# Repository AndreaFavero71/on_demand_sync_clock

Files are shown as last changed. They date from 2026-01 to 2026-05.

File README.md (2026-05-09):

# on_demand_sync_clock
On-Demand Sync Clock (OSC), an open-source, DIY smart table clock that calibrates itself with one touch of a button.

<br><br>
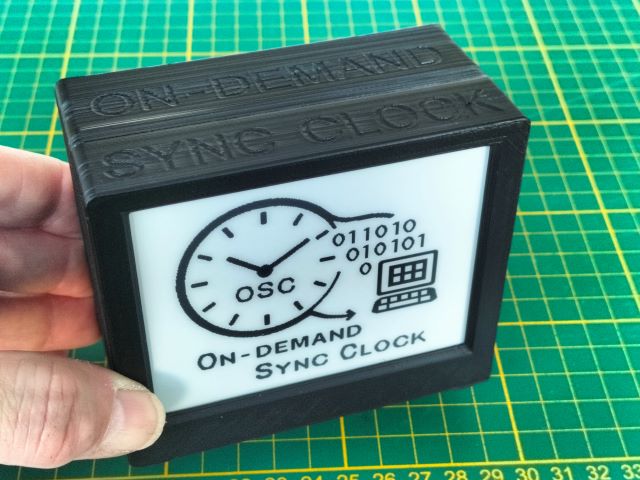
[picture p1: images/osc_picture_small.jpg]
title image
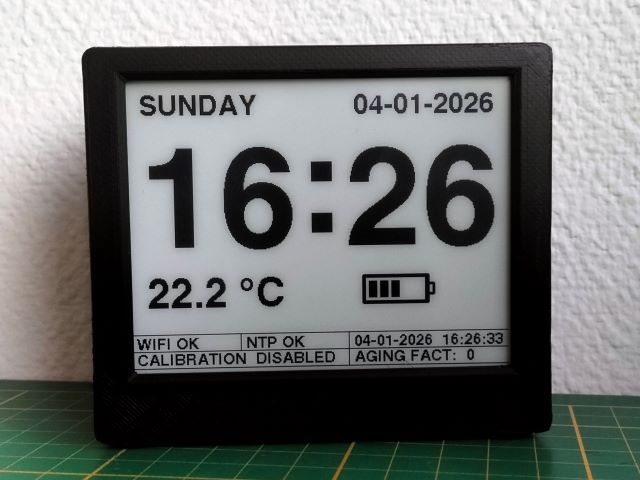
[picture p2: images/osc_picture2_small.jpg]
title image


The distinctive feature of this clock is its effortless adjustment: Simply press the push-button while an open network (Wi-Fi without password) is available, for instance, a smartphone hotspot.

Timekeeping is handled by a DS3231SN Real-Time Clock (RTC) module, which features a temperature-compensated crystal oscillator. According to the datasheet, its accuracy is within ±2 ppm (approximately ±1 minute per year).

When the button is pressed, the clock synchronizes with NTP servers. If at least 14 days have passed since the previous sync, it also calculates the drift and automatically adjusts the DS3231SN’s internal aging factor to improve long-term accuracy.

This automatic calibration is particularly handy, as many DS3231 chips on the market (in all versions, SN included) are clones with lower precision.

In short, the On-demand Sync Clock (OSC) is a DIY smart table clock that synchronizes with NTP servers on-demand via a button press, calibrates its RTC drift automatically, and runs for months on a battery.

This makes the OSC a practical option for any location without permanent internet access.

<br><br>
## Repo content
- all the Micropython files
- the Gerber files to make the Connections board
- the step files

<br><br>
## Videos
Very short video of the **sync** process (https://youtu.be/xEnDS9yevQY)
Watch the Demo (https://youtu.be/xEnDS9yevQY)
<br><br><br>

Very short video of the DS3231 **calibration** process (https://youtu.be/2SDDaN3pt_c)
Watch the Demo (https://youtu.be/2SDDaN3pt_c)

<br><br><br>
## For more information
More detailed informations at my [Instructables page](https://www.instructables.com/On-demand-Sync-Clock-OSC/)

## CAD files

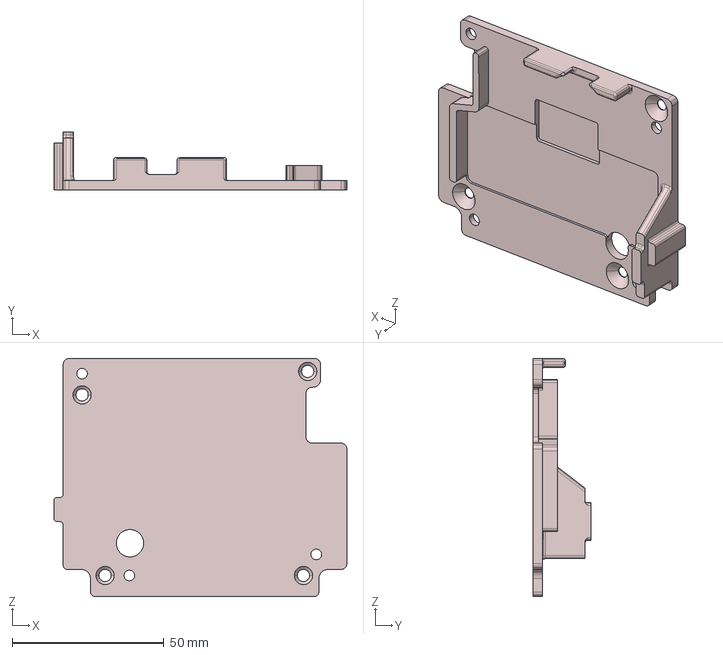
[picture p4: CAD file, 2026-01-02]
3d_model/step/panel.stp
96.5 x 19.0 x 78.4 mm

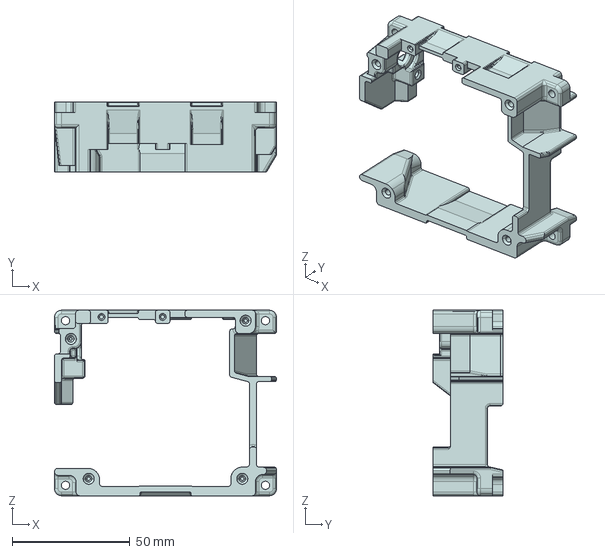
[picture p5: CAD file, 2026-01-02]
3d_model/step/frame.stp
94.4 x 29.7 x 78.9 mm

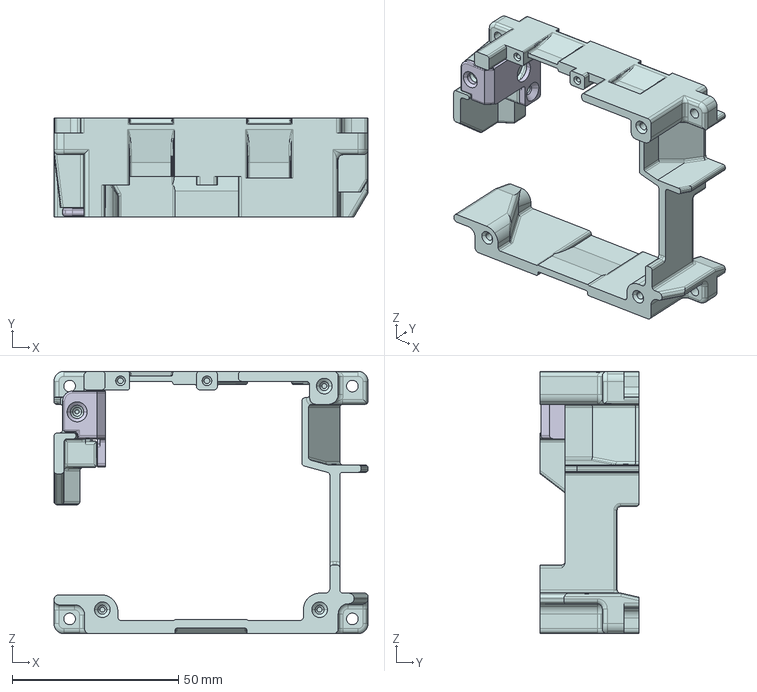
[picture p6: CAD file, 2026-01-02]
3d_model/step/btn_support.stp
94.4 x 29.7 x 78.9 mm

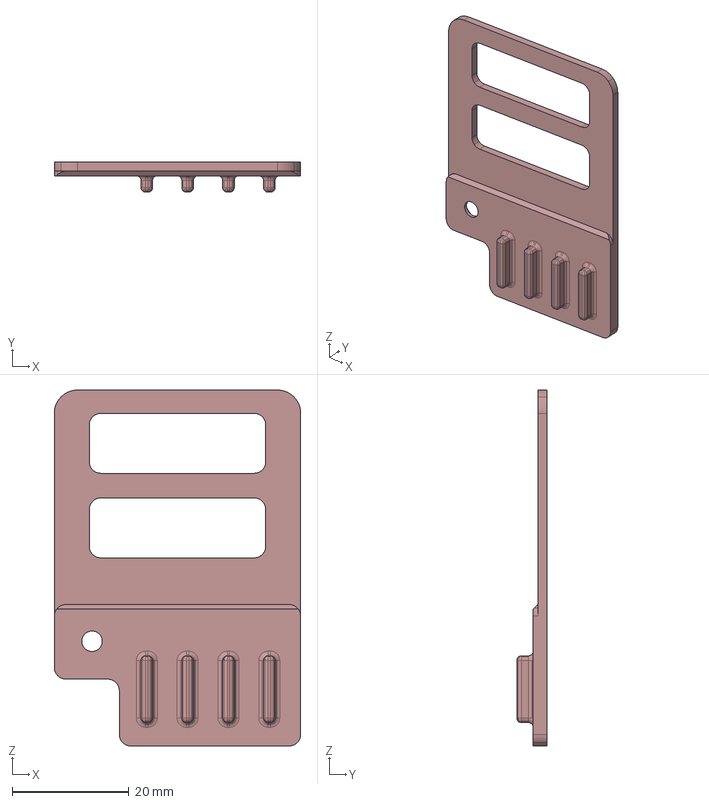
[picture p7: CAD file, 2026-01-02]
3d_model/step/clip.stp
42.3 x 5.20 x 61.0 mm

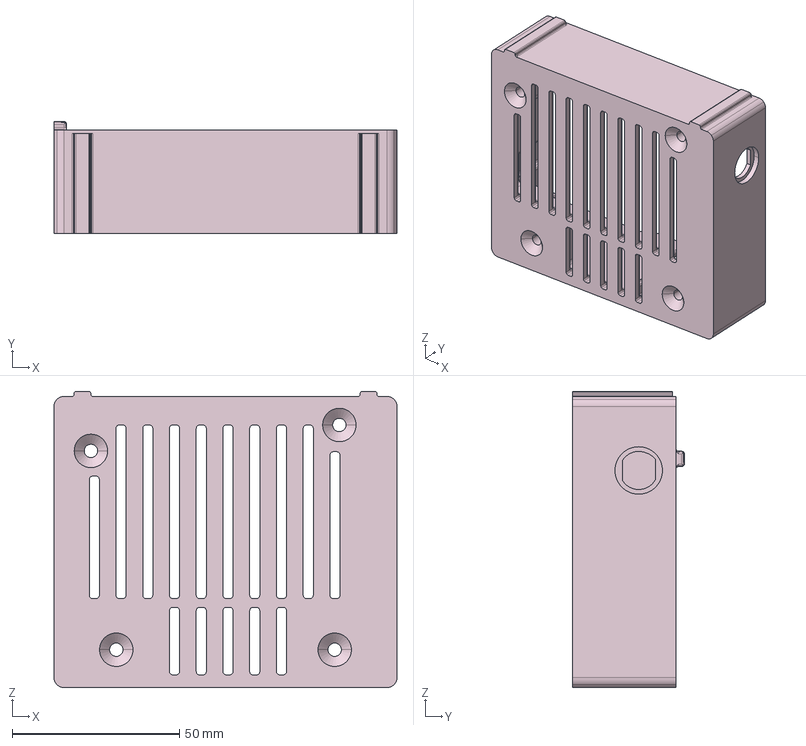
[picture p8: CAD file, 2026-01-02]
3d_model/step/back_LP785060.stp
102.6 x 33.4 x 88.6 mm

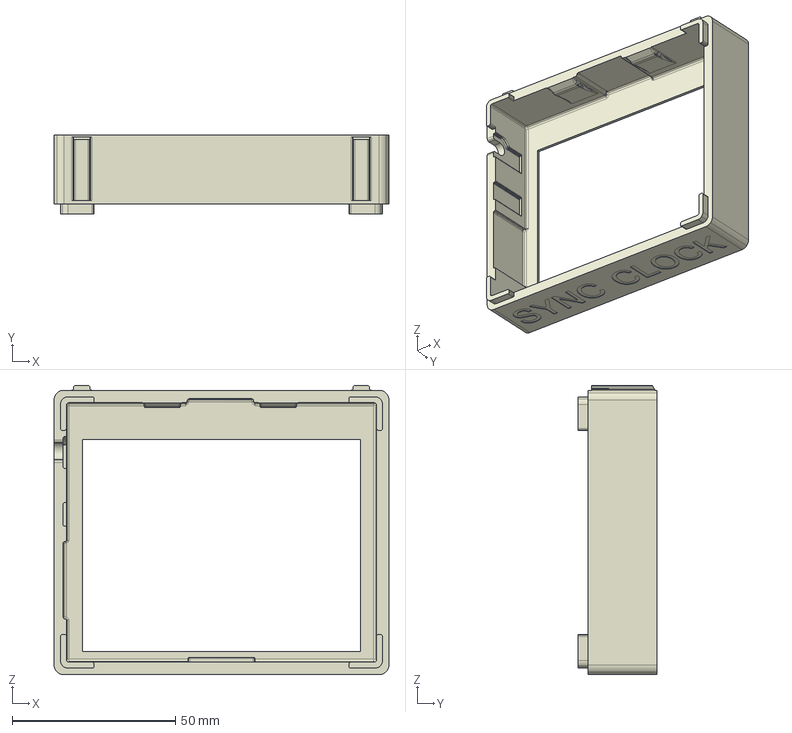
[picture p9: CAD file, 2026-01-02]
3d_model/step/front.stp
102.6 x 24.1 x 88.6 mm

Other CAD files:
3d_model/stl/btn_support.stl
3d_model/stl/clip.stl
3d_model/stl/panel.stl

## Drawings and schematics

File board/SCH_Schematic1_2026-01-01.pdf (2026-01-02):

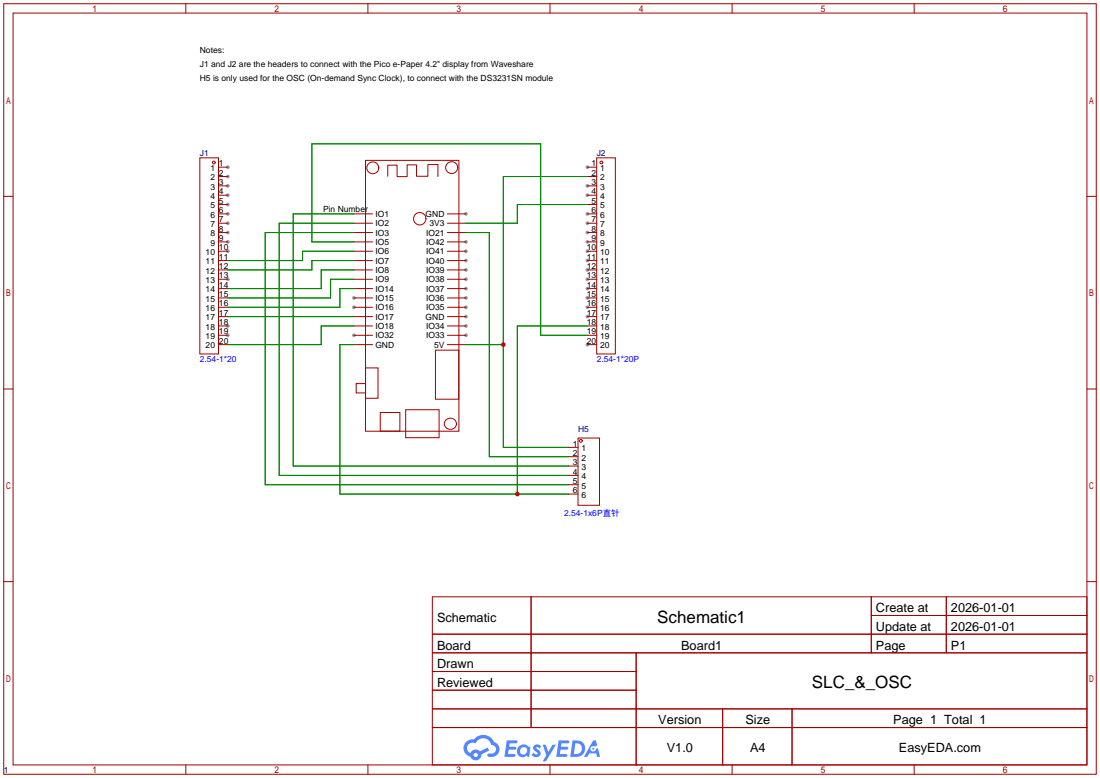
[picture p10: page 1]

Notes:
J1 and J2 are the headers to connect with the Pico e-Paper 4.2" display from Waveshare
H5 is only used for the OSC (On-demand Sync Clock), to connect with the DS3231SN module

Schematic | Schematic1 | Create at | 2026-01-01

Update at | 2026-01-01

Board | Board1 | Page | P1
Drawn | | SLC_&_OSC
Reviewed

Version | Size | Page 1 Total 1
V1.0 | A4 | EasyEDA.com

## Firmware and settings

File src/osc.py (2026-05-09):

"""
Andrea Favero 20260505

On-demand Sync Clock (OSC), a smart digital clock

The main distinctive feature is its easy sync and calibration, via
the push button and Wi-Fi coverage (also open Wi-Fi), resulting in:
- DS3231SN sync, if less than 14 days from previous sync.
- DS3231SN calibration, if more than 14 days from previous sync.


The clock is based on
- LiLyGO TTGO T8-S3 board (v1.2)      [https://tinyurl.com/3tyy9sea]
- DS3231SN module                     [https://tinyurl.com/3vp7n53h]
- WaveShare 4.2" epaper Pico display  [https://www.waveshare.com/wiki/Pico-ePaper-4.2]

High level info:
- UTC is retrieved from NTP the first time the clock runs, and on request via the push button.
- UTC is stored at the RTC DS3231.
- TZ and DST are dinamically applied on the retrieved time from the RTC DS3132, for display purpose.
- When saving UTC to theRTC, then TZ and DST are saved to NVS; This allows to precisely calculate the
  aging factor also when a DST change has happened in the meanwhile.
- No WiFi hospot is required when the clock boots after ESP32 shut-off due to low battery voltage.


More info at:
  https://github.com/AndreaFavero71/on_demand_sync_clock
  https://www.instructables.com/On-Demand-sync-Clock-OSC/


MIT License

Copyright (c) 2026 Andrea Favero

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
__version__ = "0.0.5"

# import standard modules
from utime import ticks_ms, sleep_ms, ticks_diff, mktime
from machine import Pin, freq, lightsleep
import uasyncio as asyncio
from esp32 import NVS, wake_on_ext0, WAKEUP_ANY_HIGH
import sys, gc

# import OSC custom modules
from network_manager import NetworkManager
from time_manager import TimeManager
from display_manager import Display
from battery_manager import Battery
from wdt_manager import WDTManager
from lib.config import config

# pin used to energize the DS3231ZN module
NTP_SYNC_PIN = 21


class SelfLearningClock:
    def __init__(self, logo_time_ms):
        
        print()
        print("#" * 41)
        print("#  Clock started. Press Ctrl+C to stop  #")
        print("#" * 41)
        print()
        
        # lower ESP32-S3 frequency to reduce power consumption (80MHz is the minimum for wlan operation)
        freq = 80_000_000
        
        # check / make a folder for the log related files
        self._make_folder("log")
        
        # initialize the ntp_sync_pin imput pin to start a NTP Sync
        self.ntp_sync_pin = Pin(NTP_SYNC_PIN, Pin.IN, Pin.PULL_DOWN)
        
        # enable the GPIO as a wake source from lightsleep
        wake_on_ext0(pin=self.ntp_sync_pin, level=WAKEUP_ANY_HIGH)
        
        # initialize the module for time management
        self.time_mgr = TimeManager(config)
        
        # initialize WDT manager, before the modules where it is passed
        self.wdt_manager = WDTManager()
        
        # initialize display module, by also passing the WDT manager
        self.display = Display(wdt_manager = self.wdt_manager,
                               lightsleep_active = config.LIGHTSLEEP_USAGE,
                               battery = config.BATTERY,
                               degrees = config.TEMP_DEGREES,
                               hour12 = config.HOUR_12_FORMAT,
                               am_pm_label = config.AM_PM_LABEL,
                               debug = config.DEBUG,
                               logo_time_ms = logo_time_ms
                               )
        
        self.display.plot_osc(text=False, show_ms=0, lightsleep_req=False)
        
        # initialize the network manager module, by also passing the WDT manager
        self.network_mgr = NetworkManager(self.wdt_manager, try_open_networks=config.OPEN_NETWORKS)

        # check if error from initializing the network manager
        if not self.network_mgr.secrets:
            self.display.text_on_logo("ERROR: SECRETS.JSON", x=-1, y=-1, show_time_ms=2_000)
            sys.exit(1)
            
        # initialize the battery manager module, if set at config file
        if config.BATTERY:
            self.battery = Battery(debug=config.DEBUG)
            self.batt_voltage = 0
            self.batt_level = 0

            # frequent battery check (6 minutes) when charging, otherwise less frequent (60 minutes)
            self.battery_chrg = True
        
        # initialize WDT after all components are initialized
        self.wdt_manager.initialize() 
        
        # initialize global variables: EPD refresh time is at least 60 secs (nominal)
        self.display_interval_ms = max(60_000, config.DISPLAY_REFRESH_MS)

        # state variables
        self.forced_cycle = True        # it serves as first cycle and for forced cycles (i.e. on-demand NTP sync)
        self.upload_files = False       # flag to book the file uploading task to be executed at the convenient moment
        self.enable_cal = False         # disables the self calibration until config.MIN_TIME_AUTO_CAL_H time has elapsed
        self.cycle_counter = 0          # more for fun than needed, it counts all the cycles (525600 cycles a year)
        self.display_update_count = 0   # counter to limit partial epd refreshes in between full refreshes
        
        # unit variables
        self.degrees = config.TEMP_DEGREES
        
        # aging (calibration) variable is instantiated as zero
        # It gets overruled by the aging values from esp32.NVS or DS3231
        self.aging = 0

        # arbitrary initial temperature value
        self.ds3231_temp = -999
    
    
    
    
    def get_reset_reason(self):
        """Checks the reason for the MCU boot"""
        import machine
        
        # getattr tries to get 'BROWN_OUT_RESET' from machine module. If not available, it return 6.
        BROWN_OUT_RESET = getattr(machine, "BROWN_OUT_RESET", 6)

        reset_reason = machine.reset_cause()
        
        reset_map = {
            machine.PWRON_RESET:     "POWER-ON RESET",
            machine.HARD_RESET:      "HARD RESET",
            machine.WDT_RESET:       "WATCHDOG RESET",
            machine.DEEPSLEEP_RESET: "DEEPSLEEP WAKE",
            machine.SOFT_RESET:      "SOFT RESET",
            BROWN_OUT_RESET:         "BROWNOUT RESET"
            }
        
        reset_message = reset_map.get(reset_reason, f"???: {reset_reason}")
        
        del machine
        
        return reset_reason, reset_message
    
    
    
    
    def log_reset_reason(self, reset_reason, reset_msg):
        """Writes the reset reason to a text file."""
           
        # refresh the wdt
        self.network_mgr.feed_wdt(label="write_rst_reason")
            
        try:
            datetime = await self.time_mgr.get_DS3231_time()
            
            # measure the battery voltage and related level 
            batt_voltage, batt_level = self.battery.check_battery()
            
            if datetime is None:
                datetime = ('time not known')
            
            with open(config.RESET_FILE_NAME, "a") as file:
                file.write(f"Time: {datetime},  RST_reason: {str(reset_reason)},  RST_msg: {str(reset_msg)},  Batt_volt: {str(round(batt_voltage,3))}\n")

        except OSError as e:
            print(f"[ERROR]   Failed to write reset reason: {e}")
    
    
    
    
    def _get_nvs_val(self, key, default=None, text="DEBUG"):
        """
        Read data from esp.nvs.
        Different keys are used: 'aging', 'tz_dst', 'battery_low'
        """

        try:
            nvs = NVS("app_data")
            value = nvs.get_i32(key)   # get_i32 returns an integer
            
            if config.DEBUG:
                if key == "aging":
                    print(f"[DEBUG]    Aging factor at esp32.nvs is {value}")
                
                elif key == "tz_dst":
                    print(f"[{text}]    A tz_dst (Time Zone and DST correction) was available at esp32.nvs, value: {value}")
                
                elif key == "battery_low":
                    state = True if value == 1 else False
                    print(f"[DEBUG]    Low battery flag at esp32.nvs is {state}")
            return value
        
        except OSError as e:
            print(f"[ERROR] NVS Read {key}: {e}")
            
            if e.errno == -0x1102:
                print(f"[DEBUG]    Variable '{key}' not found in esp32.NVS")
            else:
                print(f"[ERROR]    Issue on reading from esp32.NVS: {e}")
            return default
    
    
    
    
    def _set_nvs_val(self, key, value):
        """
        Wite data to esp.nvs.
        Different keys are used: 'aging', 'tz_dst', 'battery_low'
        """

        try:
            nvs = NVS("app_data")
            nvs.set_i32(key, int(value))
            nvs.commit()
            state = True if value == 1 else False
            print(f"[DEBUG]    Set {state} to the key '{key}' of esp32.NVS")
            
            return True
        except Exception as e:
            print(f"[ERROR]    NVS Save {key}: {e}")
            return False
    
    
    
    
    def goto_sleep(self, total_sleep_ms):
        """Function handling the needed steps to enter lightsleep"""
        
        # refresh the wdt
        self.network_mgr.feed_wdt(label="goto_sleep_1")

        # ensures the sleep time being positive
        total_sleep_ms = max(0, total_sleep_ms)
        
        # case lightsleep is set False
        if not config.LIGHTSLEEP_USAGE:
            # The normal sleeping function is used, instead of the light sleep
            # The sleep is done in chunk, to check the NTP button as per lighsleep
 
            if config.DEBUG:
                awake_time_ms = ticks_diff(ticks_ms(), self.t_out_sleep)
                if awake_time_ms < 1.5 * config.DISPLAY_REFRESH_MS:
                    print(f"[DEBUG]    MCU awake for {awake_time_ms} ms")
                print(f"[DEBUG]    Going to sleep for {total_sleep_ms} ms")

            sleep_chunk_ms = 10
            t_ref_ms = ticks_ms()
            wake_triggered = False
            while ticks_diff(ticks_ms(), t_ref_ms) < total_sleep_ms:
                sleep_ms(sleep_chunk_ms)
                if self.ntp_sync_pin.value():
                    t_ref2_ms = ticks_ms()
                    while self.ntp_sync_pin.value():
                        if ticks_diff(ticks_ms(), t_ref2_ms) > 250:
                            print("[DEBUG]    GPIO interrupt simulated — break sleep!")
                            wake_triggered = True
                            break
                        sleep_ms(10)
                if wake_triggered:
                    break
        
        # case lightsleep is set True
        elif config.LIGHTSLEEP_USAGE:

            try:
                # disables the wifi, otherwise the light sleep does not start
                if self.network_mgr.wlan is not None and (self.network_mgr.wlan.active() or self.network_mgr.wlan.isconnected()):
                    wlan_disabling_t_ms = self.network_mgr.disable_wifi()
                    if total_sleep_ms > wlan_disabling_t_ms:
                        total_sleep_ms -= wlan_disabling_t_ms
                    else:
                        total_sleep_ms = 0
            except Exception as e:
                if config.DEBUG:
                    print(f"[ERROR]   Issue at goto_sleep when config.LIGHTSLEEP_USAGE: {e}")
                
            
            # refresh the wdt
            self.network_mgr.feed_wdt(label="goto_sleep_2")
            

            if config.DEBUG:
                # MCU awake time (in ms)
                print(f"[DEBUG]    MCU awake for {ticks_diff(ticks_ms(), self.t_out_sleep)} ms")
                
                # MCU lighsleep time to wake up jsut in time for the minute change
                print(f"[DEBUG]    Entering lightsleep for {total_sleep_ms} ms")
                
                # force the buffer to get empyied
                sys.stdout.flush()

                # short sleep to allow the data trasmission (UART/USB); from 10ms to 50ms should do
                sleep_ms(10)
            
            # call the light sleep function, passing the sleeping time in mS
            lightsleep(total_sleep_ms)
            
            #######################################################################
            ###### DBEBUG #########################################################
            #
            # This is only for debug the lightsleep part without lighsleep function
            # It prevents the serial communication from dropping.
            # Note the display_manager.py uses lightsleep function too.
            #
            # comment out lightsleep(total_sleep_ms) above
            # uncomment command below
#             sleep_ms(total_sleep_ms)
            #
            #######################################################################
            #######################################################################
            
            if config.DEBUG:
                print(f"[DEBUG]    Quitting lightsleep")
        
        # refresh the wdt
        self.network_mgr.feed_wdt(label="goto_sleep_3")
    
    
    
    
    async def run(self):
        """Main clock execution"""
        
        # retieve the reset reason
        reset_reason, reset_msg = self.get_reset_reason()
        print(f"\n[INFO]     Last reset reason: {reset_msg}\n")
        
        # writes the reset reason in a text file for later reference
        await self.log_reset_reason(reset_reason, reset_msg)
        
        # plot the OSC logo with the OSC code version
        self.display.text_on_logo(f"OSC  VERSION:  {__version__}", x=-1, y=-1, show_time_ms=5000)
        
        # check the aging factor at the DS3231SN and at ESP32 NVS
        self.aging = await self._check_aging_factor()
        
        # set use_wifi variable as True
        use_wifi = True
        
        # case battery is set True
        if config.BATTERY:
            # check the last battery_low flag saved at the esp32.nvs
            battery_low_nvs = self._get_nvs_val(key="battery_low")
            
            # list of messages suggesting a reboot after a power outage
            reboot_msg_low_energy = ("POWER-ON RESET", "BROWNOUT RESET", "HARD RESET", "SOFT RESET")
            
            # case the battery was low and the ESP32 reset is compatible with a power outage
            if battery_low_nvs and reset_msg in reboot_msg_low_energy:
                
                # plot the OSC logo with the power otage info
                self.display.text_on_logo(f"BATTERY DIED, REBOOT", x=-1, y=-1, show_time_ms=5000)
                if config.DEBUG:
                    print()
                    print("%" *40)
                    print("%" *40)
                    print("Rebooting after a suspected power outage, no NTP check")
                    print("%" *40)
                    print("%" *40, "\n")
                
                last_ntp_s_nvs = self._get_nvs_val(key="last_ntp", default=None)
                if last_ntp_s_nvs is not None: 
                    self.ntp_datetime_str = self.time_mgr.get_dt_from_epoch(last_ntp_s_nvs)
                else:
                    # 2026-03-14, day of this code addition, is used as "last NTP sync" date
                    self.ntp_datetime_str = self.time_mgr.get_dt_from_epoch(826824718)
                    
                # set use_wifi variable to False, to skip wifi checking
                use_wifi = False
            
            # initially set the self.battery_low variable to None, later it gets updated based on the real battery voltage
            self.battery_low = None
            
            # check the battery voltage and set the battery level
            self._check_battery()
            
            # saves the time reference
            last_battery_check_ms = ticks_ms()
            

        # get the first tick, in ms (time from the board powering moment)
        tick = ticks_ms()
        
        # case use_wifi is set True
        if use_wifi:
            # plot the OSC logo with a custom text underneath
            self.display.text_on_logo("WIFI  CONNECTION  ...", x=-1, y=-1, show_time_ms=2_000)
        
            # force garbage collection
            gc.collect()
            
            # refresh the wdt
            self.network_mgr.feed_wdt(label="before making 1st wlan")
            
            # initialize WiFi
            self.network_mgr.connect_to_wifi(blocking=True)
            
            # check if error due to wifi connection
            if not self.network_mgr.wifi_bool:
                self.display.text_on_logo("ERROR: WIFI NETWORKS", x=-1, y=-1, show_time_ms=2_000)
                sys.exit(1)
        
            # check if the wifi has internet connection
            ret = await self.network_mgr.is_internet_available(blocking=True)
            
            # check if error due to internet access
            if not ret:
                self.display.text_on_logo("ERROR: NO INTERNET", x=-1, y=-1, show_time_ms=2_000)
                sys.exit(1)
        
            # refresh the wdt
            self.network_mgr.feed_wdt(label="after making 1st wlan")
        
            # check the IP addresses of the NTP server(s)
            ntp_servers_ip = await self.network_mgr.get_ntp_servers_ip(repeats=5)
        
            # check if error ar resolving the NTP servers addresses
            if len(ntp_servers_ip) == 0:
                self.display.text_on_logo("ERROR: NTP DNS", x=-1, y=-1, show_time_ms=0)
                sys.exit(1)
        
            # get the first tick, in ms (time from the board powering moment)
            tick = ticks_ms()
            
            # assign the tick to a instance variable
            self.last_display_update_ticks = tick

            # organize for the first NTP sync
            print("\n[INFO]     Performing first NTP sync ...")

            # plot the OSC logo with a custom text underneath
            self.display.text_on_logo("NTP  SYNCING ...", x=-1, y=-1, show_time_ms=500)
            
            # make the first NTP syncing, being also blocking
            ntp_epoch_s, epoch_fract_ms, sync_ticks_ms = await self.network_mgr.get_ntp_time(ntp_servers_ip, blocking=True)

            # case the real first NTP sync fails
            if ntp_epoch_s is None:
                # code is stopped
                raise Exception('First NTP synchronization failed. Halting.')
            
            # set the ntp_epoch_s to the ds3231 rtc module
            ret = await self._set_DS3231_rtc(ntp_epoch_s, epoch_fract_ms, sync_ticks_ms)
            
            # assign ntp_epoch_s to self.last_ntp_epoch_s for later calibration purpose
            self.last_ntp_epoch_s = ntp_epoch_s
            
            # saves the ntp_epoch_s to the esp32.nvs memory (for power outage cases) 
            self._set_nvs_val(key="last_ntp", value=ntp_epoch_s)
            
            # convert ntp_epoch_s in a string of date and time
            self.ntp_datetime_str = self.time_mgr.get_dt_from_epoch(ntp_epoch_s)

        # get temperature from the DS3231 module
        self.ds3231_temp = await self._get_DS3231_temperature()

        # conditional main loop variables
        if config.DEBUG:
            self.t_out_sleep = 0
        
        # main loop variables
        last_halfour_check_ms = tick
        last_hourly_check_ms = tick
        epd_refreshing_ms = 0
        sleep_time_ms = 0
        
        # instance counter for the period (hours) determining the calibration disabled / enabled
        self.hourly_counter = 0



        ########################################
        # infinite loop of the main clock code #
        ########################################
        
        print()
        print("#" * 44)
        print("#  Clock is working. Press Ctrl+C to stop  #")
        print("#" * 44)
        print()

        
        while True:

            # refresh the wdt
            self.network_mgr.feed_wdt(label="Infinite loop start")
            
            # tick (in ms) passed to most of the time-related funtions (all of those being time critical)
            current_ticks_ms = ticks_ms()
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

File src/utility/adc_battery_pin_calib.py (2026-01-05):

"""
Andrea Favero 20260103

On-demand Sync Clock (OSC)
A digital clock with on-request NTP syncing, via a push button.


Function to monitor the GPIO input voltage for ADC calibration purpose


MIT License

Copyright (c) 2025 Andrea Favero

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
from utime import time, gmtime, sleep_ms, ticks_ms, ticks_diff
from machine import Pin, ADC
import gc

from lib.lib_display import helvetica110b_digits, helvetica28b_subset
from lib.lib_display.epd4in2_V2 import EPD
from lib.lib_display.writer import Writer

EPD_WIDTH = 400
EPD_HEIGHT = 300

# settings for battery voltage check
ADC_IN = Pin(4)                     # GPIO1 reads battery voltage
adc_bat = ADC(ADC_IN)               # adc object
adc_bat.atten(ADC.ATTN_11DB)        # 11dB attenuation (input range up to ~3.3V)
V_REF = 3.3                         # ADC reference voltage (assuming ESP32 powered at 3.3V)
DIVIDER_RATIO = 2                   # voltage divider ratio:  (R2 + R41) / R41 = (100 + 100) / 100
VBAT_READINGS = 20                  # number of readings for averaging
BATTERY_CHECK_INTERVAL_S = 1        # period (in secs) in between battery level check

# constants for the ADC calibration
CORRECTION = 1.0    # default 1.0   # correction of adc reading slope vs measured (multimeter)
SHIFT = 0.0         # default 0.0   # correction of adc reading shift vs measured (multimeter)    

# Constant to prevent battery level jumping up and down between levels
HYSTERESIS_V = 0.03                 # 30 mV hysteresys from battery_level change

# battery voltage initial variabile
battery_voltage_list = []           # initialize list holdist the last voltage measurements
battery_voltage = 0                 # initialize variable holding the battery voltage
battery_level = 0                   # initialize variable holding the battery level
last_battery_level = None           # track the last battery_level
last_battery_check_time = 0         # initialize variable holding the last battery check time


def read_battery_voltage(adc_avg=0, bat_voltage=0):
    """Monitor the battery voltage"""
    try:
        adc_avg = adc_bat.read()       # first ADC reading
        sleep_ms(5)                    # Short sleep time

        for _ in range(VBAT_READINGS): # iterating VBAT_READINGS times
            adc_avg += adc_bat.read()  # adds raw ADC value (0-4095) for VBAT_READINGS times
            sleep_ms(10)               # short sleep time
        
        adc_avg /= (VBAT_READINGS + 1) # average the VBAT_READINGS readings
        
         # convertion to batt voltage and correction
        bat_voltage = SHIFT + CORRECTION * (adc_avg / 4095) * V_REF * DIVIDER_RATIO
        return bat_voltage             # returns the measured battery voltag

    except Exception as e:
        print(f"Error reading battery voltage: {e}")
        return None



def get_battery_percentage(voltage):
    """
    Returns the battery percentage corresponding to the closest voltage level.
    Args:
        voltage (float): The measured battery voltage.
    Returns:
        int: The battery percentage that best matches the voltage.
    """
    voltage_levels = [4.1, 3.93, 3.82, 3.75, 3.7, 3.65, 3.6]
    percent_levels = [100, 80,   60,   40,   20,  10,   0]

    # find the index of the voltage level closest to the measured voltage
    closest_index = min(range(len(voltage_levels)), key=lambda i: abs(voltage - voltage_levels[i]))
    new_level = percent_levels[closest_index]
    
    # if this is the first measurement, return directly
    if last_battery_level is None:
        return new_level

    # find index of the last level
    try:
        last_index = percent_levels.index(last_level)
    except ValueError:
        last_index = closest_index

    # hysteresis logic
    if new_level > last_level:
        # only go up if voltage exceeds next threshold + hysteresis
        next_up_v = voltage_levels[last_index - 1] if last_index > 0 else voltage_levels[0]
        if voltage >= next_up_v + HYSTERESIS_V:
            return new_level
        else:
            return last_level

    elif new_level < last_level:
        # only go down if voltage goes below next threshold - hysteresis
        next_down_v = voltage_levels[last_index + 1] if last_index < len(voltage_levels) - 1 else voltage_levels[-1]
        if voltage <= next_down_v - HYSTERESIS_V:
            return new_level
        else:
            return last_level

    else:
        return last_level



def check_battery(now, battery_voltage, battery_voltage_list, battery_level, last_battery_check_time,
                  BATTERY_CHECK_INTERVAL_S, first_time = False):

    if first_time or now > last_battery_check_time + BATTERY_CHECK_INTERVAL_S:
        battery_voltage = round(read_battery_voltage(),3) # battery voltage is measured   
        battery_voltage_list.append(battery_voltage)
        
        if len(battery_voltage_list) > 1:
            battery_voltage = sum(battery_voltage_list) / len(battery_voltage_list)
        
        if len(battery_voltage_list) > 10:
            battery_voltage_list.pop(0)
            
        battery_level = get_battery_percentage(battery_voltage)
        last_battery_level = battery_level
        
        last_battery_check_time = time()
    
    return battery_voltage, battery_voltage_list, battery_level, last_battery_check_time


def show_data(volt, batt_level, run, partial=True):
    
    # corrdinates to organize the fields on the screen
    ref_x = 110
    ref_y = 90
    y_shift = 30
    
    # add a white rect to erase old day text
    epd.fill_rect(0, 0, 399, 299, 1)                 
    
    # measurement counter
    Writer.set_textpos(epd, 270, 10)
    wri_28.printstring(f"MEASURE: {run}", invert=True)
    
    # measured voltage at GPIO input pin
    Writer.set_textpos(epd, ref_y, ref_x)
    wri_28.printstring(f"{round(volt,3):.3f} VOLT", invert=True)
    
    # interpreted battery level
    Writer.set_textpos(epd, ref_y + 2*y_shift, ref_x)
    wri_28.printstring(f"{batt_level} %", invert=True)

    # intermittent line separation to substantiate
    if run % 2 == 0:
        Writer.set_textpos(epd, ref_y+y_shift, ref_x)
        wri_28.printstring("----------------", invert=True)
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

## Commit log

2026-01-02 first release
    [back_LP785060.stp, btn_support.stl, btn_support.stp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]
2026-01-06 Improve WiFi handling and error logging in OSC
    Added checks for NoneType on wlan before accessing its methods in both network_manager.py and osc.py to prevent potential exceptions. Wrapped WiFi disabling logic in osc.py with a try-except block and added debug error logging. Updated version and documentation links in osc.py.
    [boot.py, osc.py]
2026-01-19 Add STEP and STL files for frame_18650 model
    Introduces 3D model files for the frame_18650 component in both STEP (.stp) and STL (.stl) formats, supporting CAD and 3D printing workflows.
    [Frame_18650.stl, frame_18650.stp]
2026-01-19 Remove frame_18650 3D model files
    Deleted the STEP and STL files for the frame_18650 model from the 3d_model directory (wrong repository...)
    [Frame_18650.stl, frame_18650.stp]
2026-01-24 Improve OSC aging factor calibration and update docs
    Enhanced debug output and logic for aging factor calibration and synchronization between DS3231SN and ESP32 NVS in osc.py. Updated documentation and improved user prompts in change_aging_factor.py. Fixed pin assignments and clarified instructions for manual aging factor entry.
    [change_aging_factor.py, osc.py]
2026-05-09 Solved DSC bug, Refactor battery, RTC, NVS and display
    Multiple functional refactors and feature additions across battery, time, display, RTC driver and main app:
    - src/osc.py: Bump version, refactor reset reason handling, consolidate NVS access into _get_nvs_val/_set_nvs_val (new keys used for aging, tz_dst, battery_low, last_ntp), add battery-aware startup flow (skip WiFi/NT P when recovering from power outage), persist last NTP to NVS, more frequent battery checks while charging, integrate new display signature, save/restore values and debug/info prints; various control-flow and stability improvements; solved bug in DSC management.
    - src/lib/battery_manager.py: Improve ADC calibration p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
    [osc.py]
